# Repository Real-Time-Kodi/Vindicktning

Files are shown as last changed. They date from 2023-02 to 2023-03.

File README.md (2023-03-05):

# Vindicktning
This board is designed to fit within the case of the Ikea Vindriktning and
replicate its functionality while replacing the main MCU with an ESP8266 for
home automation use. It also adds multiple i2c headers for adding other air 
quality sensors.  
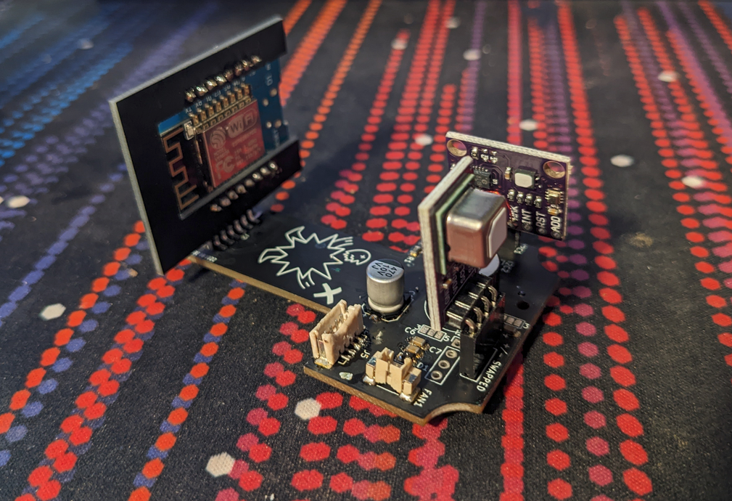
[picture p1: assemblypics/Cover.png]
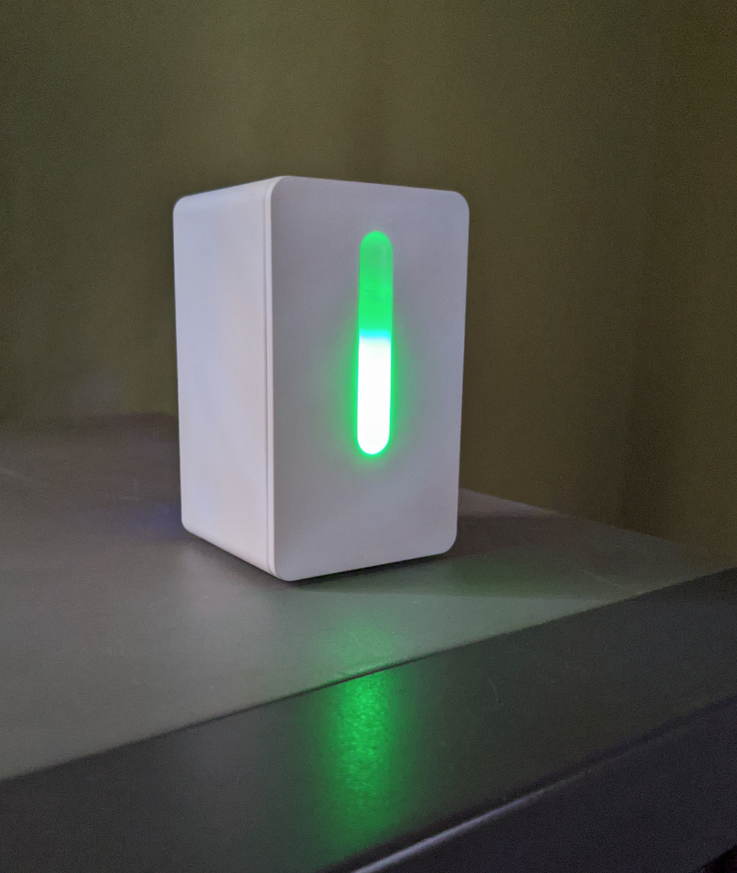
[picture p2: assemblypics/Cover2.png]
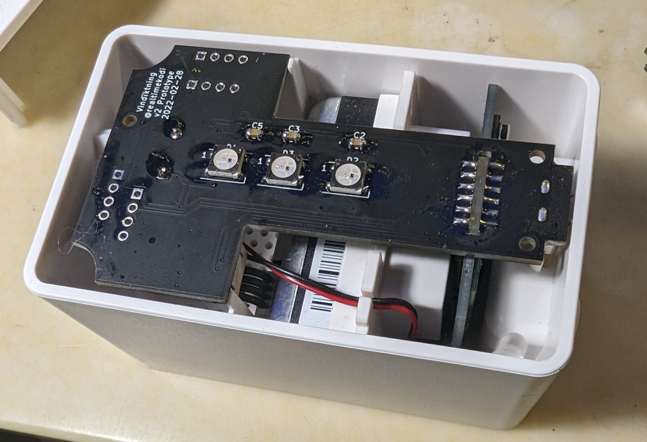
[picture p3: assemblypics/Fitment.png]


# Harvesting Components
This step is relatively straightforward, I recommend using a soldering 
hotplate and a pinecil or similar small, temperature controlled iron.
The first step is to harvest the parts you'll need from the Vindriktning
 board. Remove all of the components circled in red. The easiest way to do this
 is to scrape the LEDs off of the underside of the board and put it on the
hotplate, removing each component with tweezers once the board is good and hot.  
You'll need both of the connectors, the electrolytic cap, and the diode.

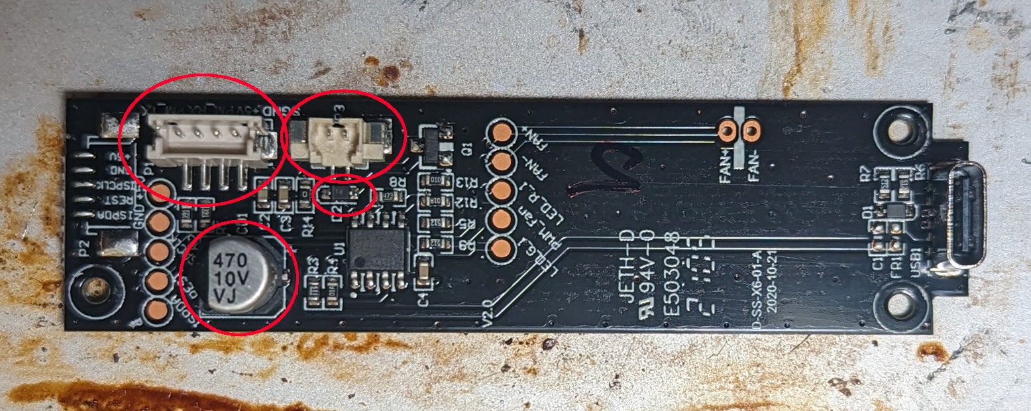
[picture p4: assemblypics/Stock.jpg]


# Parts List
- [Usb Type C Connector](https://www.mouser.com/ProductDetail/640-USB4120-03-C)
- 7x 0805 0.1uf Capacitors
- 3x WS2812b LEDs
- 1x 0805 10k Resistor(optional for buzzer)
- 1x [MMBT2222](https://www.mouser.com/ProductDetail/241-MMBT2222AR100001) SOT Transistor or equivalent(optional for buzzer)
- 1x Standard buzzer(optional)
- Fine wire(Optional for USB data hookup)
- Wemos D1 Mini  

I have a few kits available on my [tindie page](https://www.tindie.com/products/realtimekodi/vindriktning-air-quality-sensor-mod-boardesphome/#shipping).  

# Board Assembly
Using your preferred method, solder each of the components on to their 
designated pads. All of the capacitors are 0.1uf except for the electrolytic 
capacitor. Mind the polarity on both the capacitor and the diode!

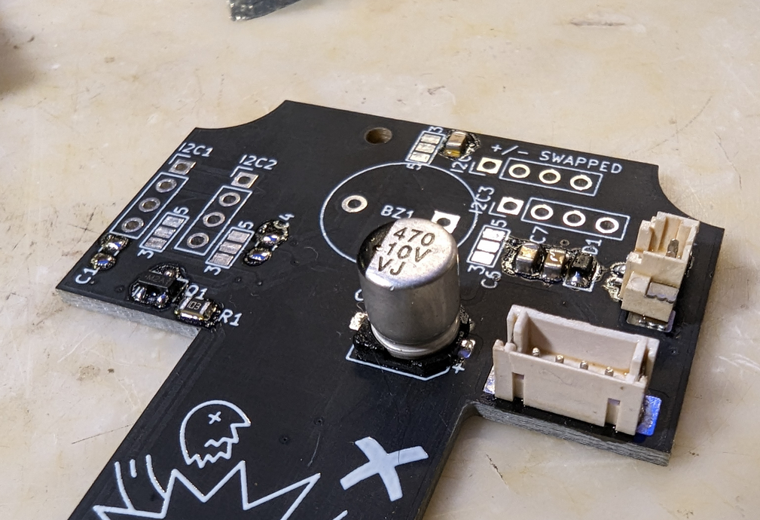
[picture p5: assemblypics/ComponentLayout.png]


I recommend using the hotplate for all of the surface mount components and
verifying that you get 5v at this point before proceeding to the next steps.
Don't forget to solder the LEDs on the back.

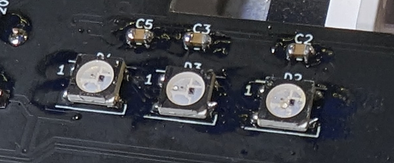
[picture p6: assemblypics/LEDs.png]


The other board is easy to get wrong. Make sure the port and board are
facing the correct direction or the completed assembly will not fit into the
case! Look at the pictures to be sure of orientation. The ESP module on the 
Wemos D1 should fit into the board cutout and the USB port should be accessible.
Solder the boards together with small bits of wire or header pins.

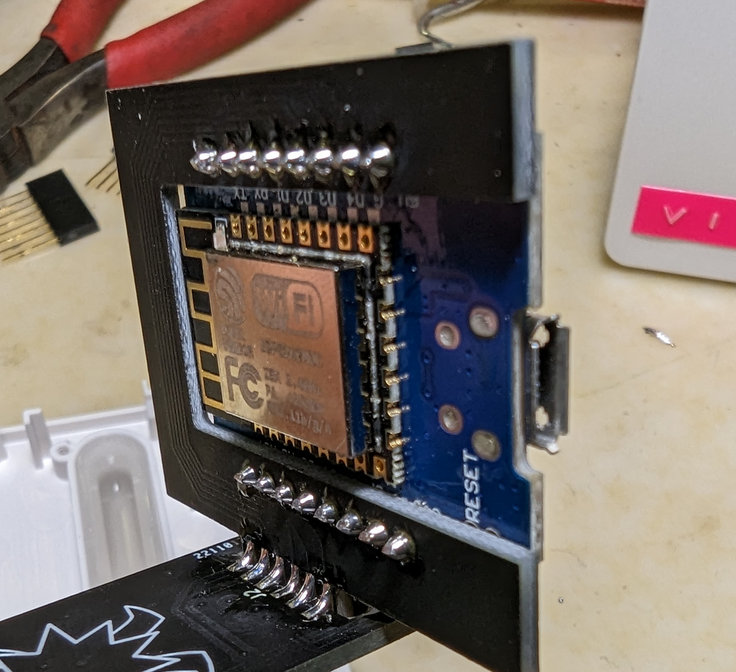
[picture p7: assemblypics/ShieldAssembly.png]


It is easiest to solder the through-hole components before mating the boards 
together, this is the point where you should install the optional buzzer and 
any i2c headers you wish to use. The headers should have been included with the 
Wemos D1 and can be cut down to size with angle cutters.

# Mating the Boards
The board containing the Wemos D1 must be facing exactly as shown. Insert it 
into the slot and solder it on BOTH SIDES, making sure that it is exactly
perpendicular to the main PCB. Test the fitment before Reassembly!

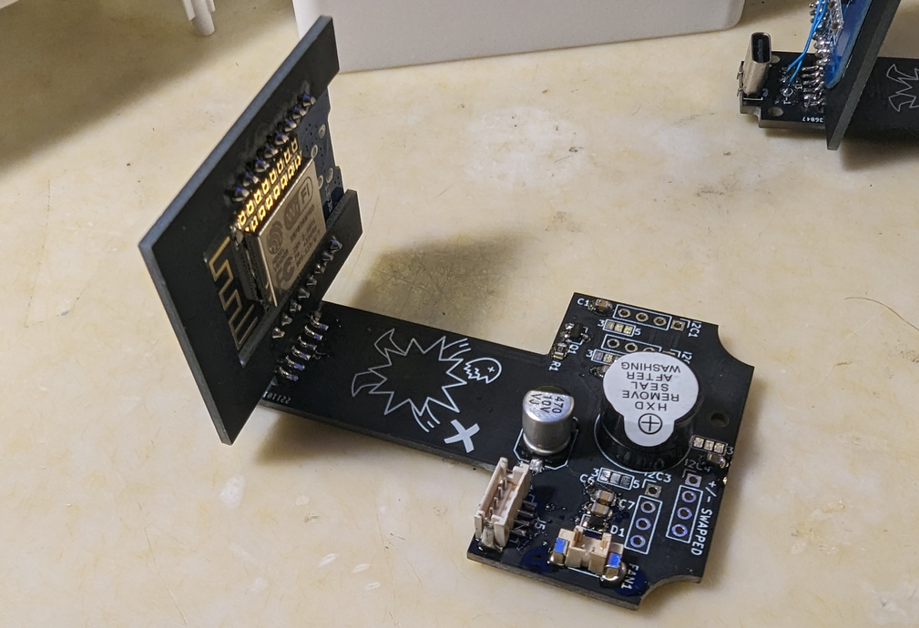
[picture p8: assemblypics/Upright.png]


# USB Data lines for External Programming(Optional)
There are two labeled test pads on the main PCB (D+ and D-) those two pads can
be connected to the corresponding D+ and D- pins on the Wemos D1's USB to Serial chip to allow
you to program the device without opening it up. There are several different USB -> Serial chips on the
D1. Check the diagram below for specific pinout. Many modules will have the model numbers sanded off of
the CH341. Note that this is not a valid implementation of USB and the type-c cable will only be able to 
program the device when inserted right-side up.

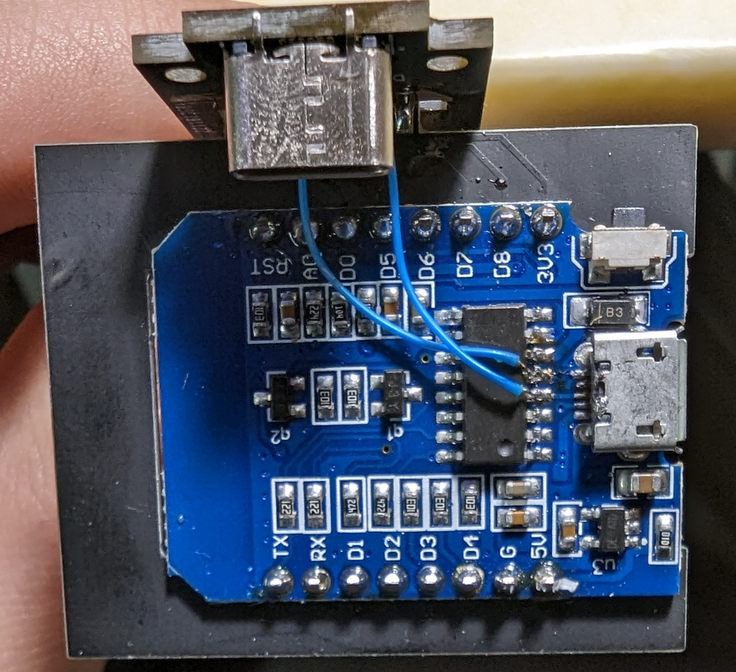
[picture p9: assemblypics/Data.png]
  
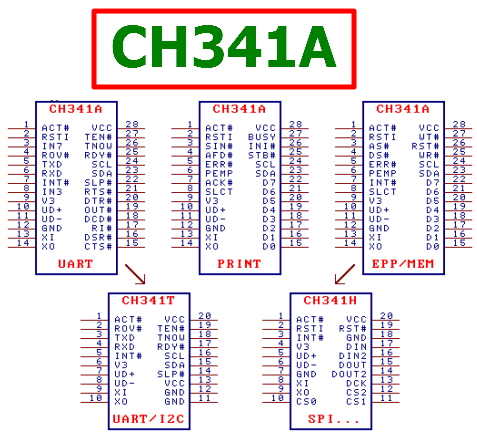
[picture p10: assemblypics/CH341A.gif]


# Reassembly
The Vindrictning top case needs to have these 2 standoffs removed. Flush 
cutters work best.

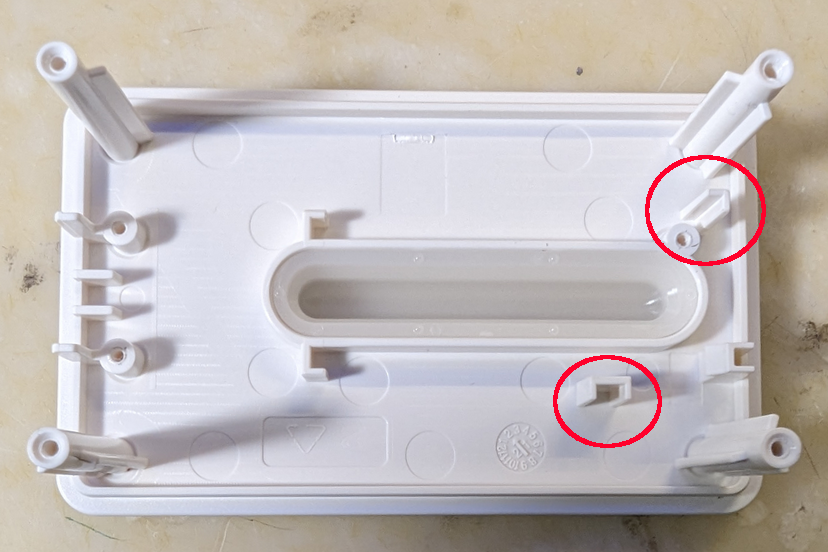
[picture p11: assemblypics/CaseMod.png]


The new board can then be installed with the screws that 
came with the vindriktning. Keep an eye on the header pins that hold the 
Wemos D1 to its pcb, they need to be trimmed as flush as possible in order for 
the board to clear the fan screws.

# Programming
See the included esphome example. It initializes all of the inbuilt perpherals 
and has a function for fading the LEDs between colors based on the c02, pm2.5, 
and VOC concentrations. Program it with whichever method you usually use to 
program ESPHome devices.  
Please remember that the usb port will only connect the data pins with the type-c 
connector in the upward orientation.  

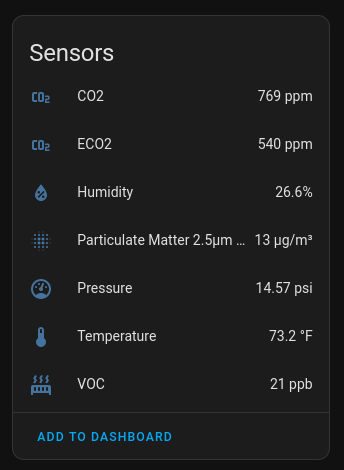
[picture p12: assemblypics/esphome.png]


# Adding I2C Sensors
Additional sensors can be added using the I2C headers. There are three of them of them
with the following pinout: SDA | SCL | GND | VCC  
The I2C4 header on the top of the board has positive and negative swapped so that it 
can be used with [this sensor](https://www.amazon.com/gp/product/B0BHHRT1F6/): 
SDA | SCL | VCC | GND  
The voltage is 3.3 by default but it can be set to 5v by cutting the voltage selector
trace and adding a solder blob on the 5v side. The silkscreen is clearly labled.

Check [ESPHome.io](https://esphome.io/) for supported sensors and configuration
documentation.

Sensors I have used:
- SCD40 (CO2)
- BME280 (Temperature Humiditity Pressure)
- BME680
- BMP280 (Temperature Pressure)
- CCS811 (eC02 Volatile Organic Compounds)

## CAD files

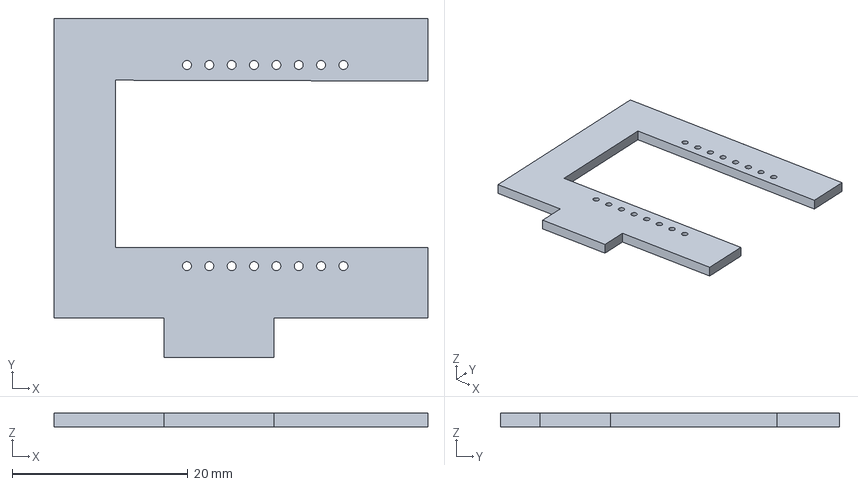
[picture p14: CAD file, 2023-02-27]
d1shield/d1shield.step
42.5 x 38.5 x 1.60 mm
SLW-108-01-G-S x 2
TSW-108-05-G-S x 2

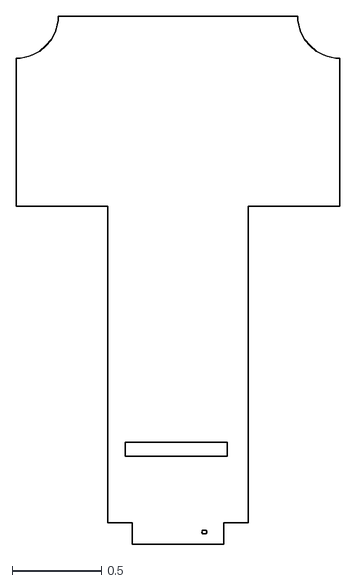
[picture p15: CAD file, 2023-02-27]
vindick/dxf/vindick-Edge_Cuts.dxf
1.81 x 2.95

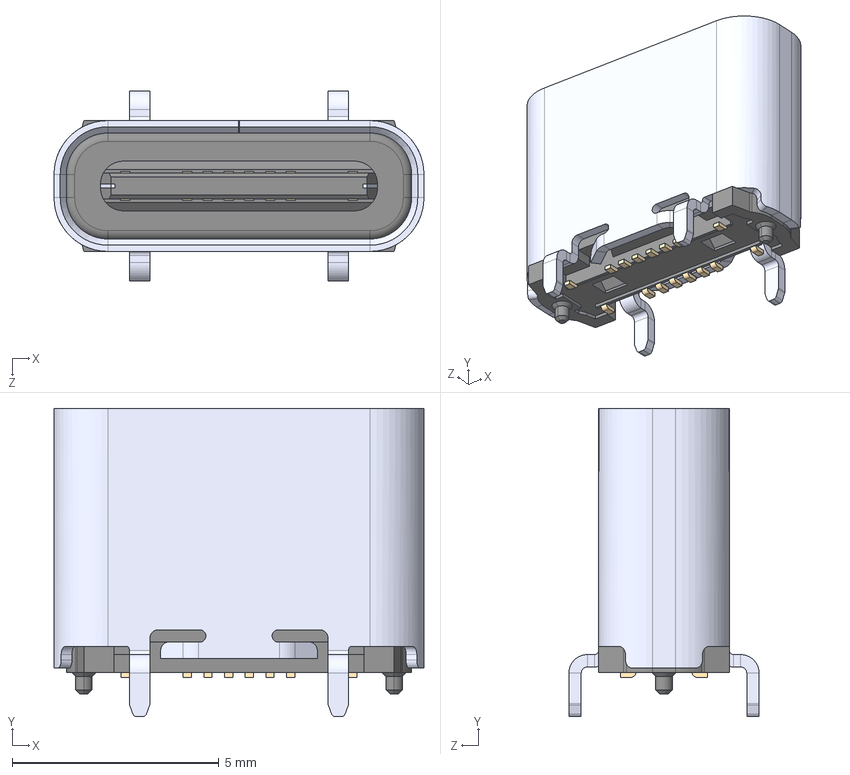
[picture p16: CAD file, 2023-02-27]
vindick/USB4120-03-C_REVA.step
8.94 x 7.45 x 4.60 mm

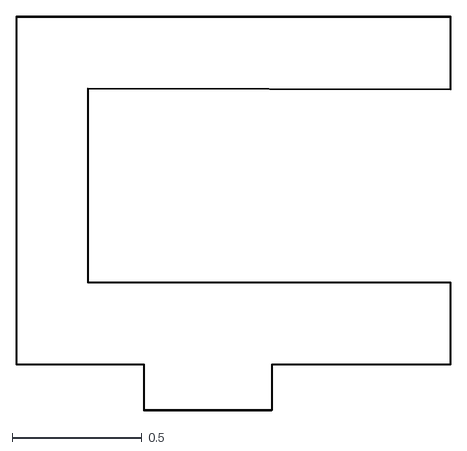
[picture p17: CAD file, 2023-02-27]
d1shield/d1shield-Edge_Cuts.dxf
1.68 x 1.52

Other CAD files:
vindick/dxf/vindick-B_Adhes.dxf
vindick/dxf/vindick-B_Paste.dxf
vindick/dxf/vindick-F_Paste.dxf

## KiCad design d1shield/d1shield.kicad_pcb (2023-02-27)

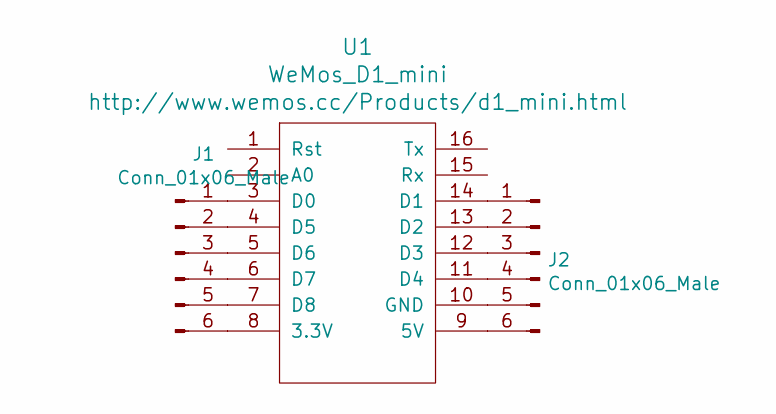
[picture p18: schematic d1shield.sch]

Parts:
J1, J2: Conn_01x06_Male; Edge
U1: WeMos_D1_mini; wemos-d1-mini-connectors-only

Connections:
unnamed: J1.1, U1.3 (D0)
unnamed: J1.2, U1.4 (D5)
unnamed: J1.3, U1.5 (D6)
unnamed: J1.4, U1.6 (D7)
unnamed: J1.5, U1.7 (D8)
unnamed: J1.6, U1.8 (3.3V)
unnamed: J2.1, U1.14 (D1)
unnamed: J2.2, U1.13 (D2)
unnamed: J2.3, U1.12 (D3)
unnamed: J2.4, U1.11 (D4)
unnamed: J2.5, U1.10 (GND)
unnamed: J2.6, U1.9 (5V)

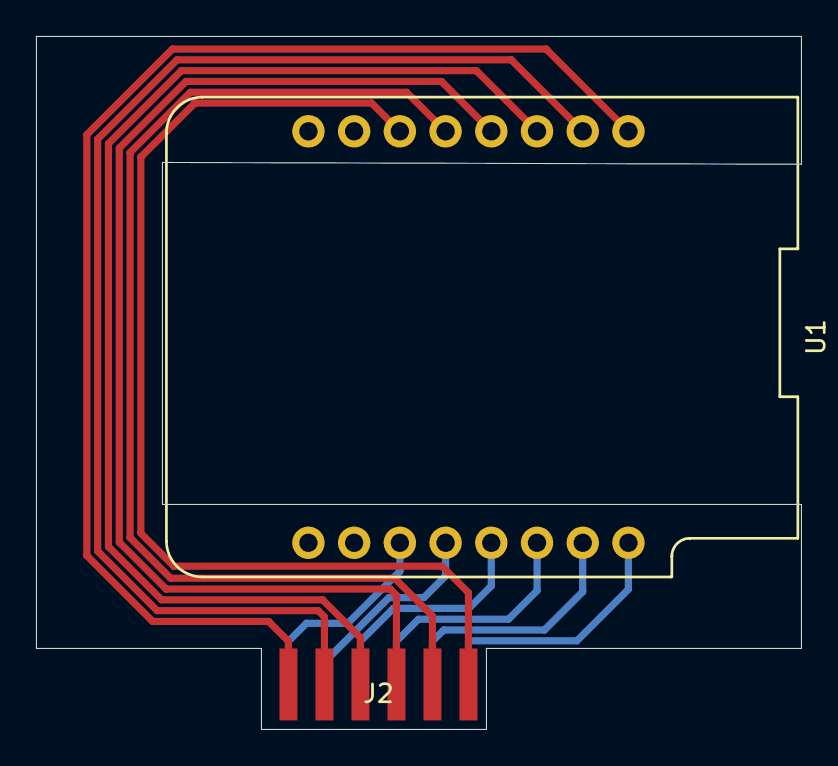
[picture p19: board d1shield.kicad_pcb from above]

Board: 2 copper layers, 42.5 x 38.5 mm, 3 parts (1 on the bottom side), 12 nets.

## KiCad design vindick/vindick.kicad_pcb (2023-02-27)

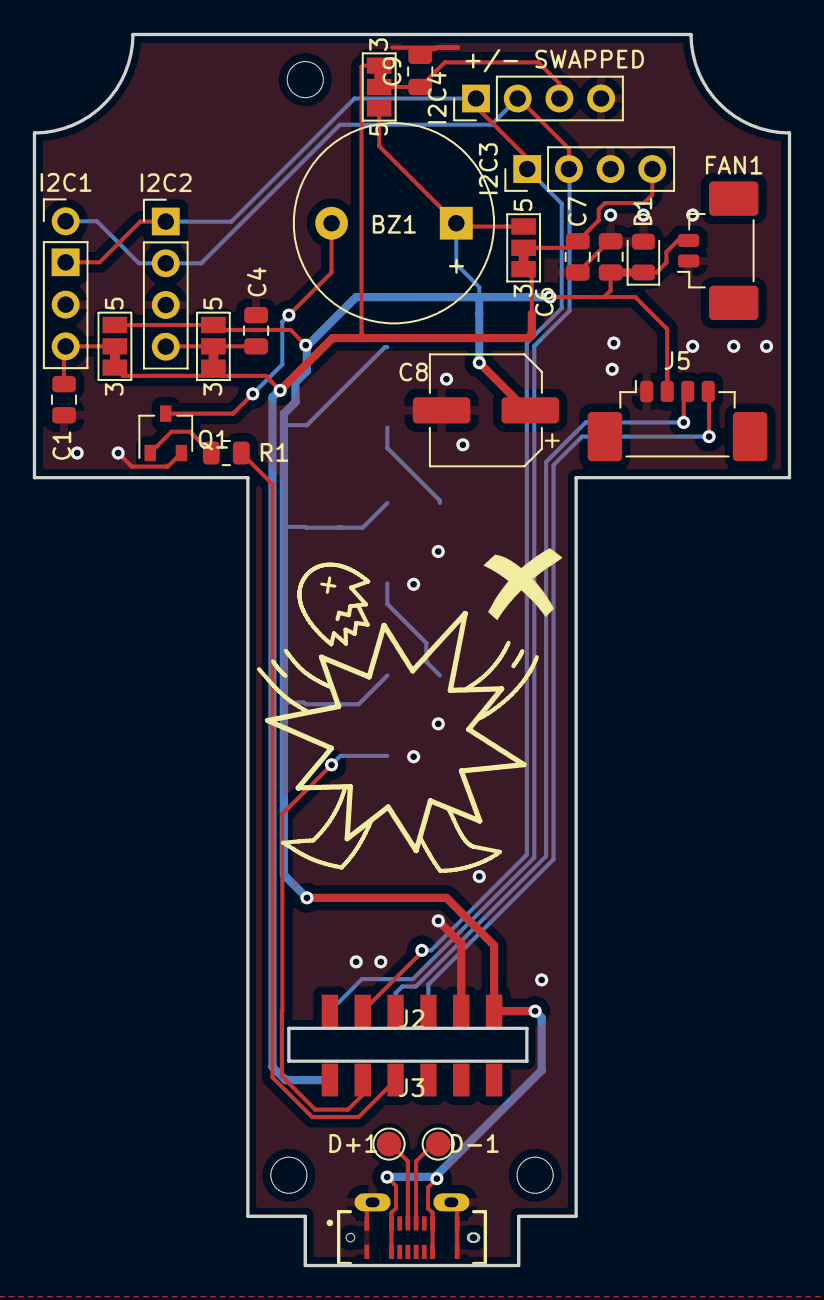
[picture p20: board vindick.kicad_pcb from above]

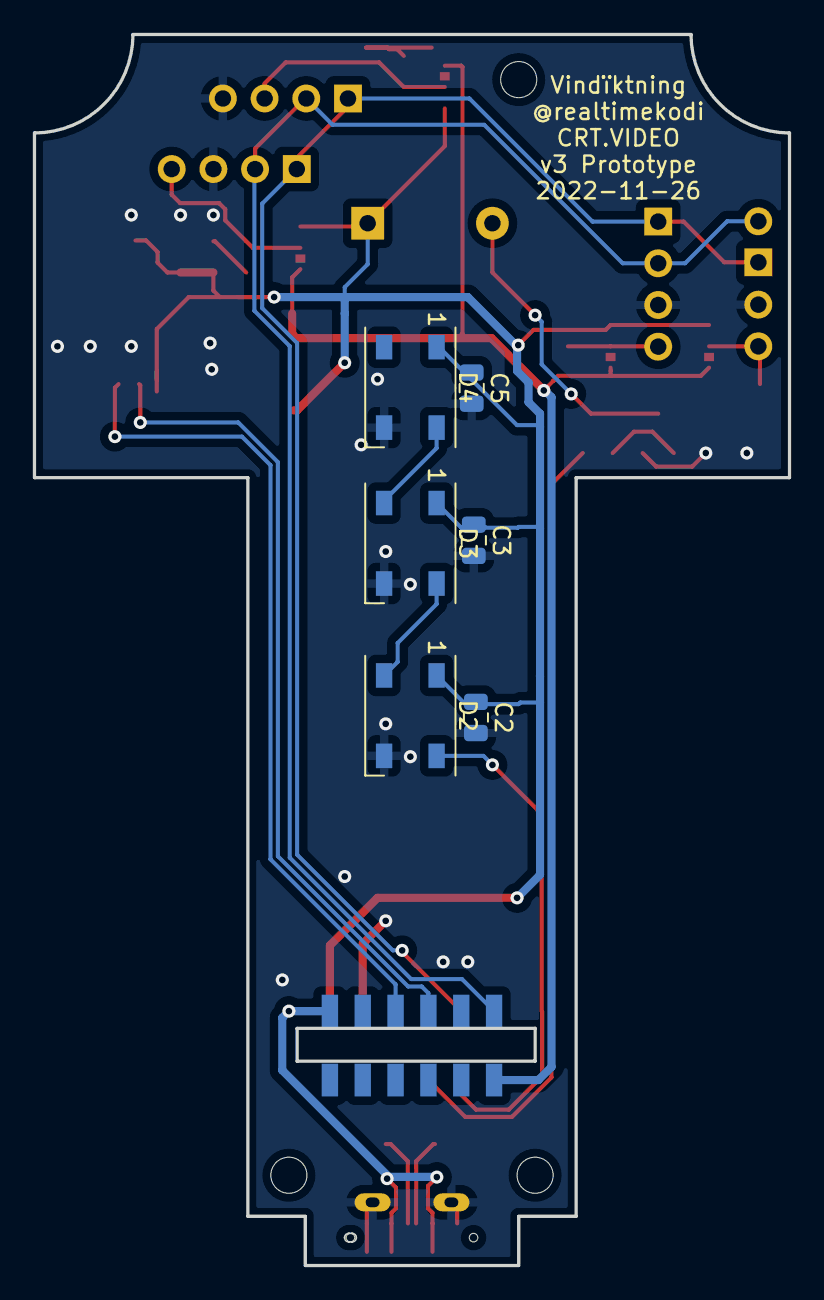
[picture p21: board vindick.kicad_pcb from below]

Board: 2 copper layers, 46.0 x 75.0 mm, 31 parts (6 on the bottom side), 19 nets.

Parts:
BZ1: Buzzer; Buzzer_12x9.5RM7.6
C1, C2, C3, C4, C5, C6, C7, C9: C; C_0805_2012Metric
C8: CP; CP_Elec_6.3x7.7
D1: D; D_0805_2012Metric
D2, D3, D4: WS2812B; LED_WS2812B_PLCC4_5.0x5.0mm_P3.2mm
D+1: D+; TestPoint_Pad_D1.5mm
D-1: D-; TestPoint_Pad_D1.5mm
FAN1: PicoBlade 2; Molex_PicoBlade_53398-0271_1x02-1MP_P1.25mm_Vertical
I2C1, I2C3, I2C4: Conn_01x04_Male; PinHeader_1x04_P2.54mm_Vertical
I2C2: I2C1; PinHeader_1x04_P2.54mm_Vertical
J1: USB4120-03-C_REVA; GCT_USB4120-03-C_REVA
J2: TopSide; Edgesmol
J3: USB Side; Edgesmol
J5: Conn_01x04_Male; Molex_PicoBlade_53398-0471_1x04-1MP_P1.25mm_Vertical
JP1, JP2, JP3, JP4: 3/5; SolderJumper-3_P1.3mm_Bridged12_Pad1.0x1.5mm_NumberLabels
Q1: Q_NPN_BEC; SOT-23W
R1: R; R_0805_2012Metric

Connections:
+3V3: J3.6, JP1.1 (A), JP2.1 (A), JP3.1 (A), JP4.1 (A)
/BUZZ: J3.4, R1.2
/D+: D+1.1, J1.A6 (D1+), J1.B6 (D2+)
/D-: D-1.1, J1.A7 (D1-), J1.B7 (D2-)
/LIGHT: D2.4 (DIN), J3.5
/RXD: J2.4, J5.3
/SCL: I2C1.2, I2C2.2, I2C3.2, I2C4.2, J2.6
/SDA: I2C1.1, I2C2.1, I2C3.1, I2C4.1, J2.5
/TXD: J2.3, J5.4
GND: C1.2, C2.2, C3.2, C4.2, C5.2, C6.2, C7.2, C8.2, C9.2, D1.2 (A), D2.3 (VSS), D3.3 (VSS), D4.3 (VSS), FAN1.1, I2C1.3, I2C2.3, I2C3.3, I2C4.3, J1.A1 (GND_A), J1.A12 (GND_A), J1.B1 (GND_B), J1.B12 (GND_B), J1.S1 (SHIELD), J1.S3 (SHIELD), J2.2, J5.1, Q1.2 (E)
unnamed: BZ1.2 (+), Q1.3 (C)
unnamed: C1.1, I2C1.4, JP1.2 (C)
unnamed: C4.1, I2C2.4, JP2.2 (C)
unnamed: C6.1, I2C3.4, JP3.2 (C)
unnamed: C9.1, I2C4.4, JP4.2 (C)
unnamed: D2.2 (DOUT), D3.4 (DIN)
unnamed: D3.2 (DOUT), D4.4 (DIN)
unnamed: Q1.1 (B), R1.1
VBUS: BZ1.1 (-), C2.1, C3.1, C5.1, C7.1, C8.1, D1.1 (K), D2.1 (VDD), D3.1 (VDD), D4.1 (VDD), FAN1.2, J1.A4 (VBUS_A), J1.A9 (VBUS_A), J1.B4 (VBUS_B), J1.B9 (VBUS_B), J2.1, J5.2, JP1.3 (B), JP2.3 (B), JP3.3 (B), JP4.3 (B)

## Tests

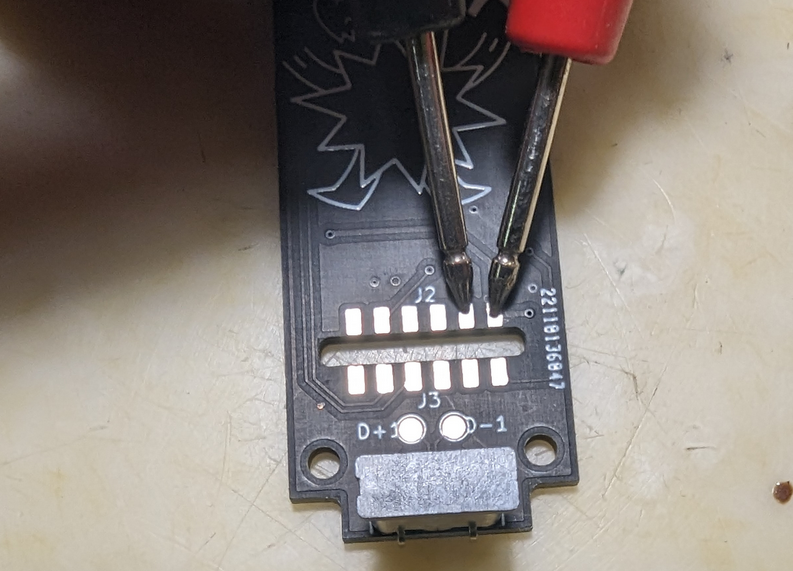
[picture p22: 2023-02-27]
assemblypics/Testpoint.png

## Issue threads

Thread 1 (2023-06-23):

D2 scavenged diode

Reddog176, 2023-06-23:
What is the value of the d2 scavenged diode? I couldn't find polarity markings on the board, nor on your photos. So I need to replace the diode.

Real-Time-Kodi, 2023-06-23:
D1 can be any general purpose diode. if you plug in the fan, make note of the positive red wire and place the anode facing the red wire and the cathode facing the black wire.

you should be able to test the polarity of the scavenged diode with a multimeter

Closed 2023-07-06.

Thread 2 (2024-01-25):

Board needs 8 capacitors.

jbabio, 2024-01-25:
Hello. I'm assembling the board I've purchased from your tindie store and found that it needs 8 0805 0.1uf SMD capacitors. The readme.md states that only 7 are needed (and sent with the kit).

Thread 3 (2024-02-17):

PCB Available somewhere?

hongkongkiwi, 2024-02-17:
Hey, can I buy the PCB from somewhere? I don't need the kit just the PCB.

Real-Time-Kodi, 2024-02-25:
I just killed the product on the shop. Best way to get some is to order from pcbway or jclpcb or dirtypcbs.
I'll add the gerbers to the repo. You just need to send both sets of gerbers to your PCB house of choice and wait.

hongkongkiwi, 2024-02-25:
Awesome! The gerbers would be great.

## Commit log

2023-02-27 Initial PCB Commit
    [USB4120-03-C_REVA.step, d1shield-Edge_Cuts.dxf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]
2024-01-17 Fixed pm2.5 sensor startup behaviour
2024-02-25 Added gerbers since the shop is gone
